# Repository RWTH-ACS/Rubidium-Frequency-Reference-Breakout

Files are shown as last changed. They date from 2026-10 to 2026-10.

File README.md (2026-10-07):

# Low-Cost Rubidium-Based Clock Reference

This project contains a hardware breakout board for an FE-5680A frequency reference, including a Python web UI to control the frequency offsets and monitor the PPS and Lock signal.

A detailed explanation is given in the publication proceedings of ISPCS 2026 (Low-Cost Rubidium-Based Clock Reference and Pulse-Per-Second Jitter Evaluation)

## Hardware

The hardware breakout board provides multiple decoupled 10 MHz outputs to allow for easy use in a laboratory environment. It also has a pulse per second output that is controllable in its pulse width.

## Software

The software stack allows for a simple control of the RFS via a Raspberry Pi. A USB to RS232 adapter that is connected to the RFS was utilized.

## License

This software is licensed under the Apache open-source license, while the hardware is under the CERN-OHL-W-2.0 open source license. Please refer to the license file in the `LICENSE` in the hardware and software directory.

We kindly ask all academic publications employing components of this work to cite the following paper:

For other licensing options please consult [Prof. Antonello Monti](mailto:amonti@eonerc.rwth-aachen.de).

## Contact

EONERC ACS Logo (http://www.acs.eonerc.rwth-aachen.de)

- Manuel Pitz <manuel.pitz@eonerc.rwth-aachen.de>
- Sebastian Uerlich <sebastian.uerlich@eonerc.rwth-aachen.de>
- Benish Khan <benish.khan@eonerc.rwth-aachen.de>
- Leonid Kalinin <leonid.kalinin@rwth-aachen.de>

[Institute for Automation of Complex Power Systems (ACS)](http://www.acs.eonerc.rwth-aachen.de)
[EON Energy Research Center (EONERC)](http://www.eonerc.rwth-aachen.de)
[RWTH University Aachen, Germany](http://www.rwth-aachen.de)

## Acknowledgment

This research has received funding from the European Union’s Horizon Europe research and innovation programme under grant agreement No 101172829. Views and opinions expressed are however those of the author(s) only and do not necessarily reflect those of the European Union or CINEA. Neither the European Union nor the granting authority can be held responsible for them.

We are grateful for the financial support of the [BMWE (Federal Ministry of Economic Affairs and Energy)](https://www.bundeswirtschaftsministerium.de/Navigation/EN/Home/home.html), funding reference [03EI6125A](https://www.enargus.de/pub/bscw.cgi/?op=enargus.eps2&q=beaver&v=10&id=243841191).

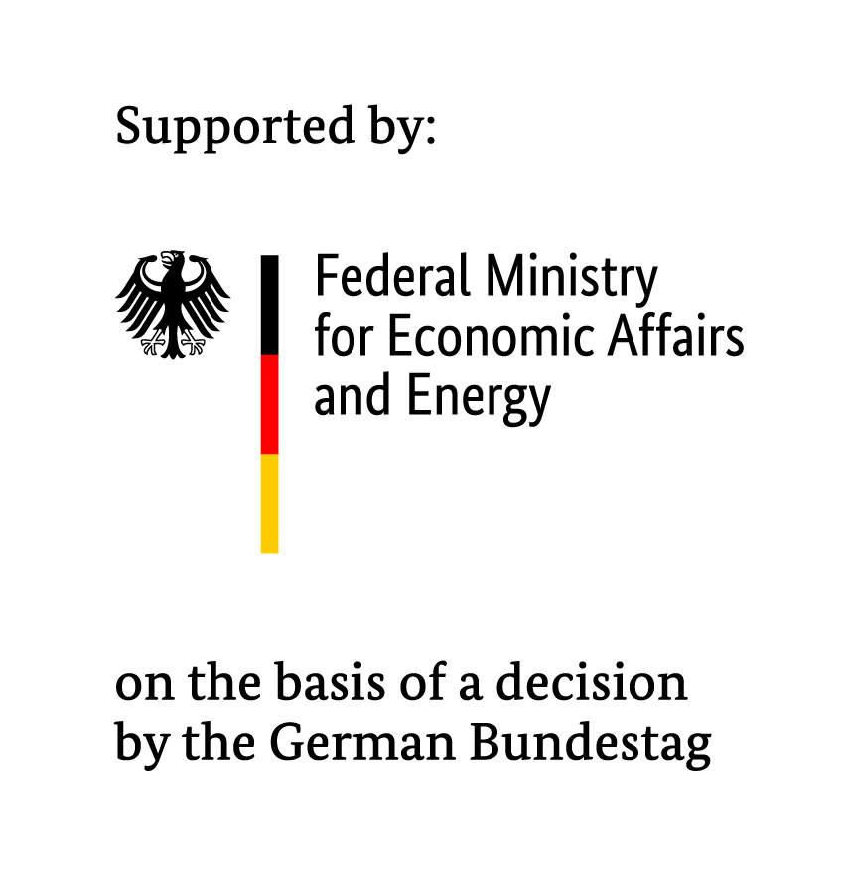
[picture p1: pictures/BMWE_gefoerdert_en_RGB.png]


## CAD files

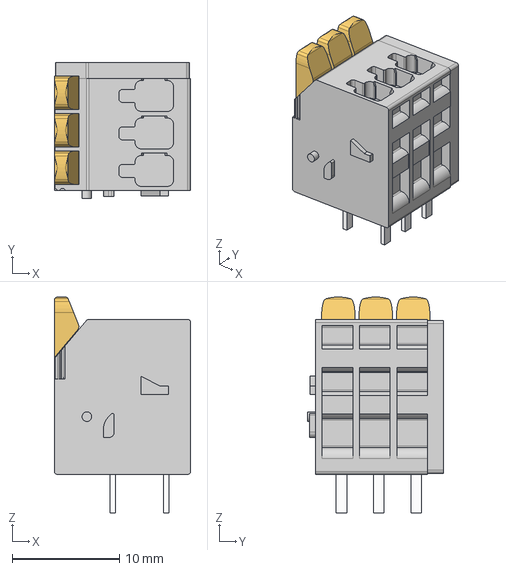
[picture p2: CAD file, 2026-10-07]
hardware/3d/2601-3103.step
12.8 x 12.8 x 20.2 mm

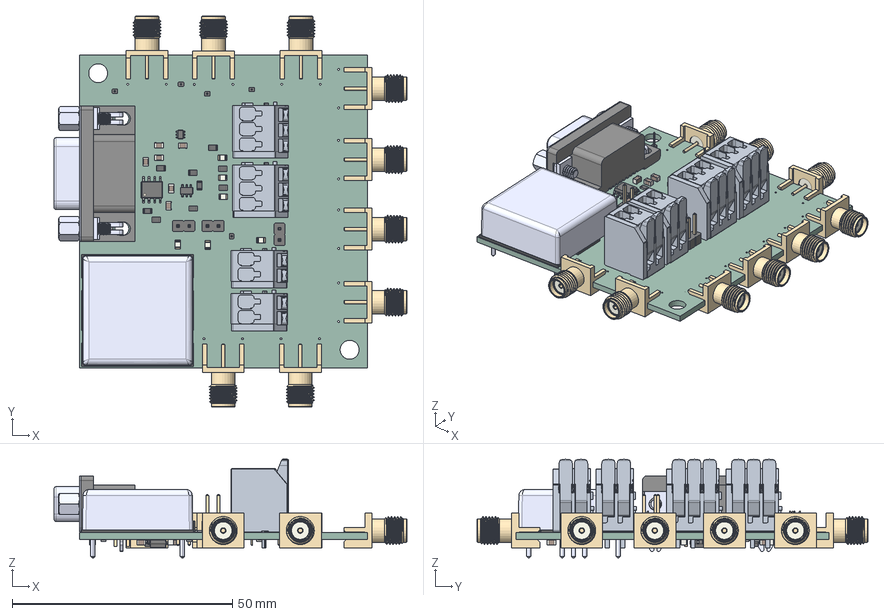
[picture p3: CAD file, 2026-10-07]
hardware/FT-5680A_interface.step
80.1 x 88.8 x 22.4 mm
SOIC-8_3.9x4.9mm_P1.27mm x 2
LED_0805_2012Metric x 6
R_0805_2012Metric x 20
SMA_Molex_73251-1153_EdgeMount_Horizontal x 9
PinHeader_1x01_P1.00mm_Vertical x 5
C_0805_2012Metric x 15
PinHeader_1x02_P2.54mm_Vertical x 3
thn15_3d_drawing
TSOT-23-6
SOT-363_SC-70-6
A-DF 09 A_KG-T2S_A-DF 09 A_KG-T2S
SSOP-16_3.9x4.9mm_P0.635mm
SOT-23-6
FT-5680A_interface_PCB

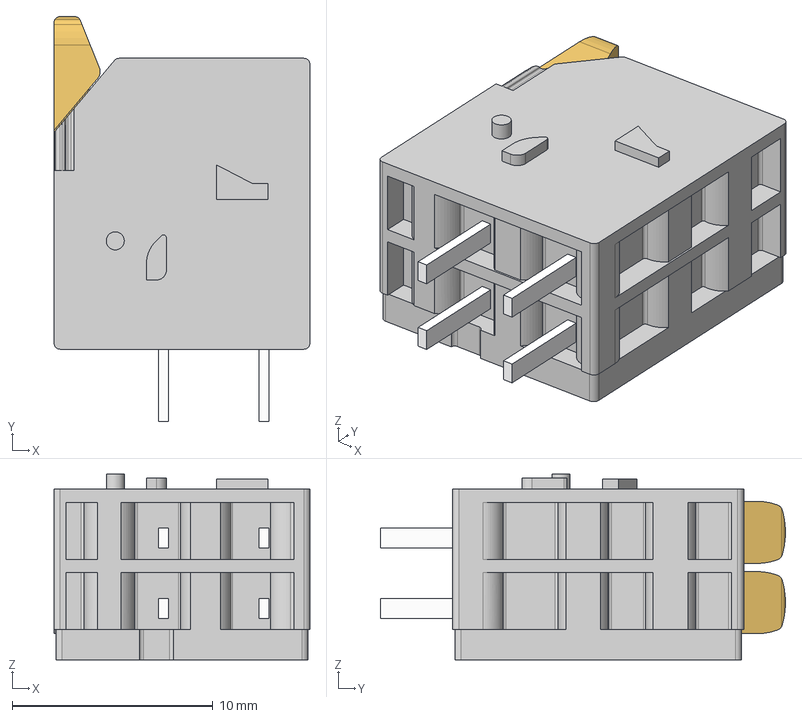
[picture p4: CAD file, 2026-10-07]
hardware/3d/2601-3102.step
12.8 x 20.2 x 9.25 mm

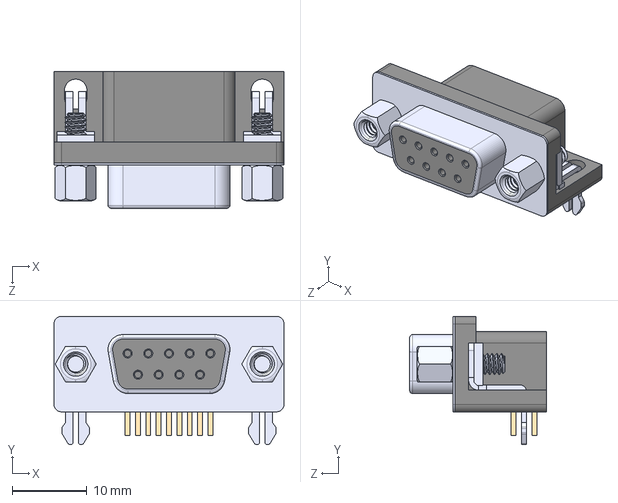
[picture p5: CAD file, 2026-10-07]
hardware/3d/A-DF_09_A_KG-T2S.step
30.8 x 17.2 x 18.3 mm

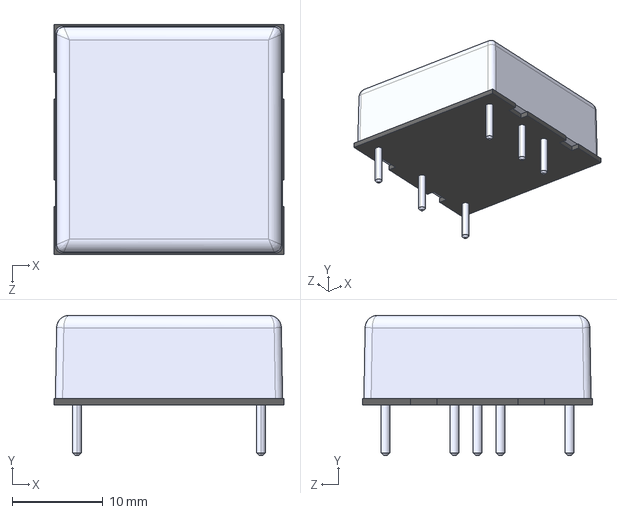
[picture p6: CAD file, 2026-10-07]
hardware/3d/thn15_3d_drawing.stp
25.4 x 15.5 x 25.4 mm

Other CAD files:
hardware/3d/2601-3102.igs
hardware/3d/2601-3103.igs

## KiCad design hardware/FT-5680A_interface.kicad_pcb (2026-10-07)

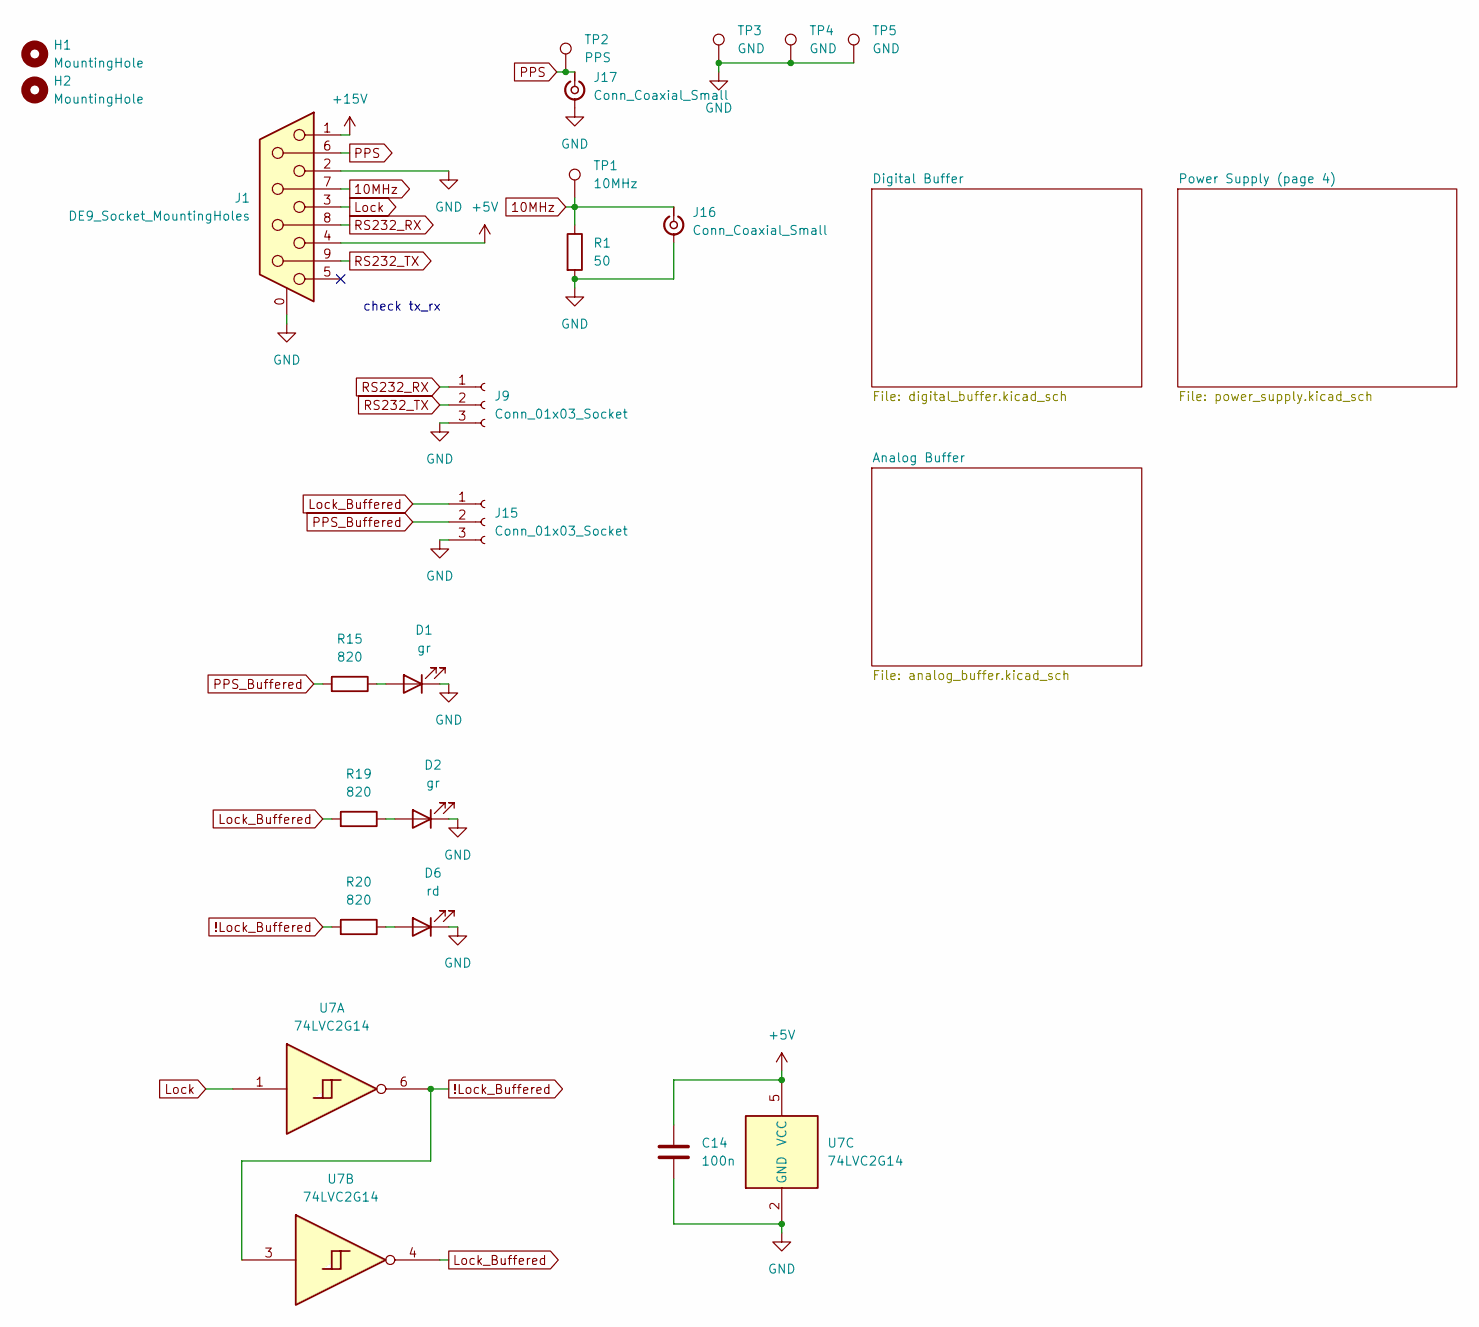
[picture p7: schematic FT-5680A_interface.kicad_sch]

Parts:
C14: 100n; C_0805_2012Metric_Pad1.18x1.45mm_HandSolder
D1, D2: gr; LED_0805_2012Metric_Pad1.15x1.40mm_HandSolder
D6: rd; LED_0805_2012Metric_Pad1.15x1.40mm_HandSolder
H1, H2: MountingHole; MountingHole_4.3mm_M4_DIN965
J1: DE9_Socket_MountingHoles; ASSMANN_A-DF_09_A_KG-T2S; Digikey AE10921-ND
J9, J15: Conn_01x03_Socket; 2601-3103; Digikey 2946-2601-3103-ND
J16, J17: Conn_Coaxial_Small; SMA_Molex_73251-1153_EdgeMount_Horizontal
R1: 50; R_0805_2012Metric_Pad1.20x1.40mm_HandSolder
R15, R19, R20: 820; R_0805_2012Metric_Pad1.20x1.40mm_HandSolder
TP1: 10MHz; PinHeader_1x01_P1.00mm_Vertical
TP2: PPS; PinHeader_1x01_P1.00mm_Vertical
TP3, TP4, TP5: GND; PinHeader_1x01_P1.00mm_Vertical
U7: 74LVC2G14; SOT-363_SC-70-6_Handsoldering; Digikey 296-13011-1-ND

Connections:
10MHz: J1.7, J16.1 (In), R1.1, TP1.1; also elsewhere on the board
!Lock_Buffered: R20.2, U7.3, U7.6
+5V: C14.1, J1.4, U7.5 (VCC); also elsewhere on the board
+15V: J1.1; also elsewhere on the board
GND: C14.2, D1.1 (K), D2.1 (K), D6.1 (K), J1.0 (PAD), J1.2, J9.3, J15.3, J16.2 (Ext), J17.2 (Ext), R1.2, TP3.1, TP4.1, TP5.1, U7.2 (GND); also elsewhere on the board
Lock: J1.3, U7.1
Lock_Buffered: J15.1, R19.2, U7.4
unnamed: D1.2 (A), R15.1
unnamed: D2.2 (A), R19.1
unnamed: D6.2 (A), R20.1
PPS: J1.6, J17.1 (In), TP2.1; also elsewhere on the board
PPS_Buffered: J15.2, R15.2; also elsewhere on the board
RS232_RX: J1.8, J9.1
RS232_TX: J1.9, J9.2

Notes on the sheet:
check tx_rx

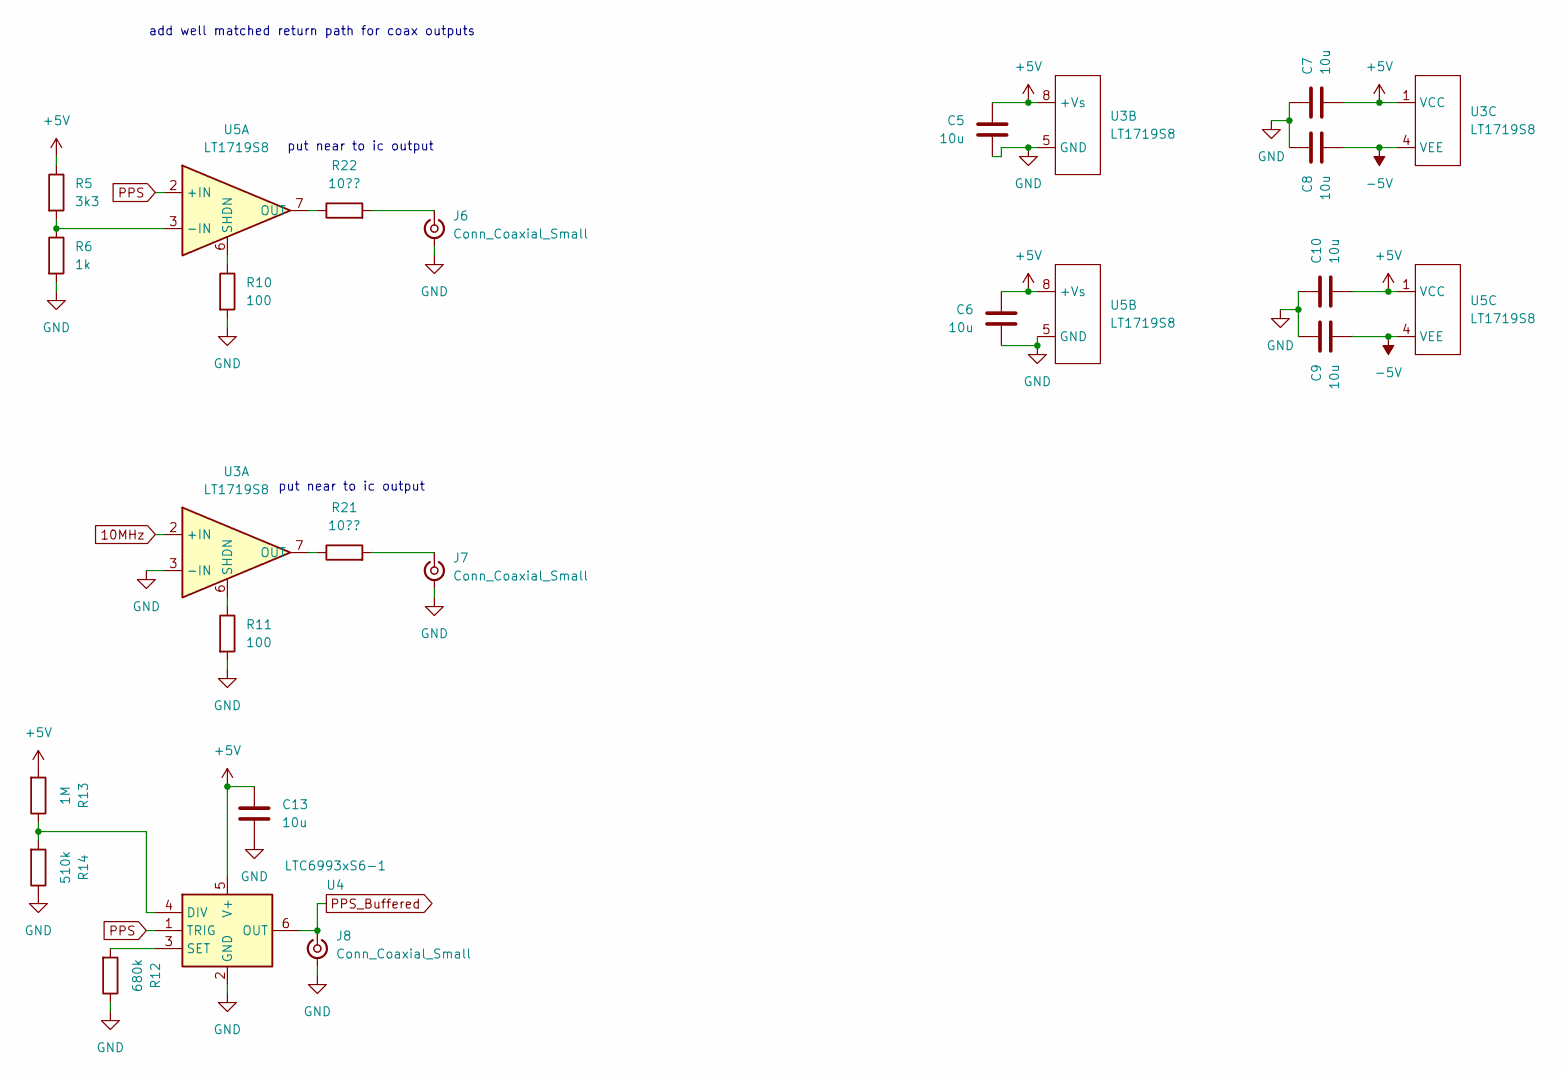
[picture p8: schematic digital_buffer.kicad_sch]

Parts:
C5, C6, C7, C8, C9, C10, C13: 10u; C_0805_2012Metric_Pad1.18x1.45mm_HandSolder
J6, J7, J8: Conn_Coaxial_Small; SMA_Molex_73251-1153_EdgeMount_Horizontal
R5: 3k3; R_0805_2012Metric_Pad1.20x1.40mm_HandSolder
R6: 1k; R_0805_2012Metric_Pad1.20x1.40mm_HandSolder
R10, R11: 100; R_0805_2012Metric_Pad1.20x1.40mm_HandSolder
R12: 680k; R_0805_2012Metric_Pad1.20x1.40mm_HandSolder
R13: 1M; R_0805_2012Metric_Pad1.20x1.40mm_HandSolder
R14: 510k; R_0805_2012Metric_Pad1.20x1.40mm_HandSolder
R21, R22: 10??; R_0805_2012Metric_Pad1.20x1.40mm_HandSolder
U3, U5: LT1719S8; SOIC-8_3.9x4.9mm_P1.27mm; Digikey 505-LT1719IS8#PBF-ND
U4: LTC6993xS6-1; TSOT-23-6_HandSoldering; Digikey 505-LTC6993HS6-1#WTRMPBFCT-ND

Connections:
10MHz: U3.2 (+IN); also elsewhere on the board
+5V: C5.1, C6.1, C7.2, C10.2, C13.1, R5.1, R13.2, U3.1 (VCC), U3.8 (+Vs), U4.5 (V+), U5.1 (VCC), U5.8 (+Vs); also elsewhere on the board
-5V: C8.2, C9.2, U3.4 (VEE), U5.4 (VEE); also elsewhere on the board
GND: C5.2, C6.2, C7.1, C8.1, C9.1, C10.1, C13.2, J6.2 (Ext), J7.2 (Ext), J8.2 (Ext), R6.2, R10.2, R11.2, R12.1, R14.1, U3.3 (-IN), U3.5 (GND), U4.2 (GND), U5.5 (GND); also elsewhere on the board
unnamed: J6.1 (In), R22.1, R22.2, U5.7 (OUT)
unnamed: J7.1 (In), R21.1, R21.2, U3.7 (OUT)
unnamed: R11.1, U3.6 (SHDN)
unnamed: R13.1, R14.2, U4.4 (DIV)
unnamed: R12.2, U4.3 (SET)
unnamed: R5.2, R6.1, U5.3 (-IN)
unnamed: R10.1, U5.6 (SHDN)
PPS: U4.1 (TRIG), U5.2 (+IN); also elsewhere on the board
PPS_Buffered: J8.1 (In), U4.6 (OUT); also elsewhere on the board

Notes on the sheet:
put near to ic output
add well matched return path for coax outputs

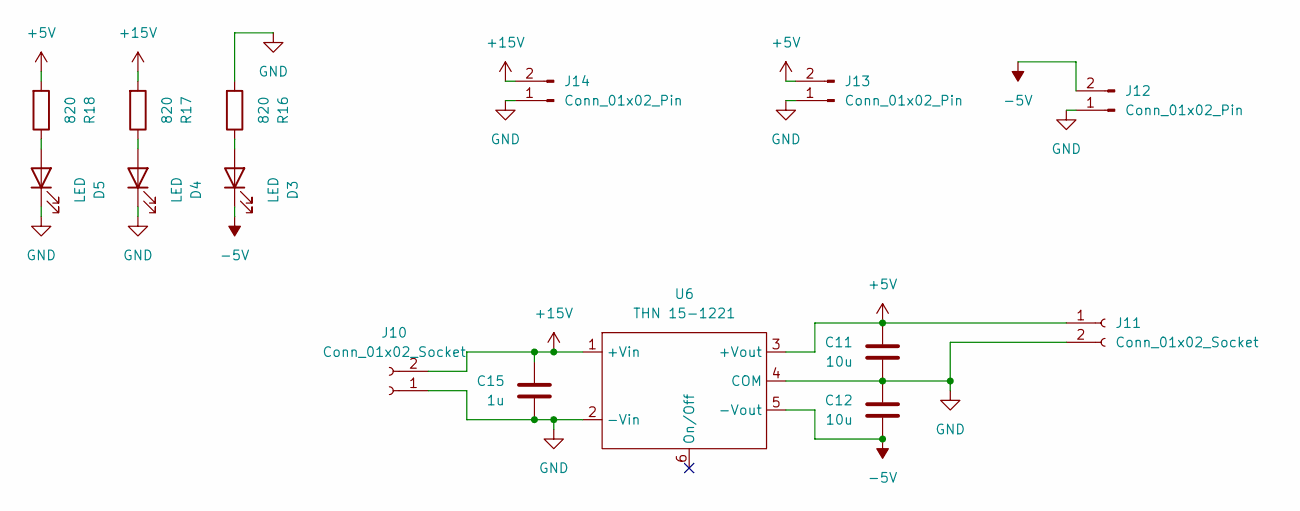
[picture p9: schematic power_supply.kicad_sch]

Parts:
C11, C12: 10u; C_0805_2012Metric_Pad1.18x1.45mm_HandSolder
C15: 1u; C_0805_2012Metric_Pad1.18x1.45mm_HandSolder
D3, D4, D5: LED; LED_0805_2012Metric_Pad1.15x1.40mm_HandSolder
J10, J11: Conn_01x02_Socket; 2601-3102; Digikey 2946-2601-3102-ND
J12, J13, J14: Conn_01x02_Pin; PinHeader_1x02_P2.54mm_Vertical
R16, R17, R18: 820; R_0805_2012Metric_Pad1.20x1.40mm_HandSolder
U6: THN 15-1221; Digikey 1951-3115-ND

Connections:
+5V: C11.1, J11.1, J13.2, R18.2, U6.3 (+Vout); also elsewhere on the board
+15V: C15.1, J10.2, J14.2, R17.2, U6.1 (+Vin); also elsewhere on the board
-5V: C12.2, D3.1 (K), J12.2, U6.5 (-Vout); also elsewhere on the board
GND: C11.2, C12.1, C15.2, D4.1 (K), D5.1 (K), J10.1, J11.2, J12.1, J13.1, J14.1, R16.2, U6.2 (-Vin), U6.4 (COM); also elsewhere on the board
unnamed: D3.2 (A), R16.1
unnamed: D4.2 (A), R17.1
unnamed: D5.2 (A), R18.1

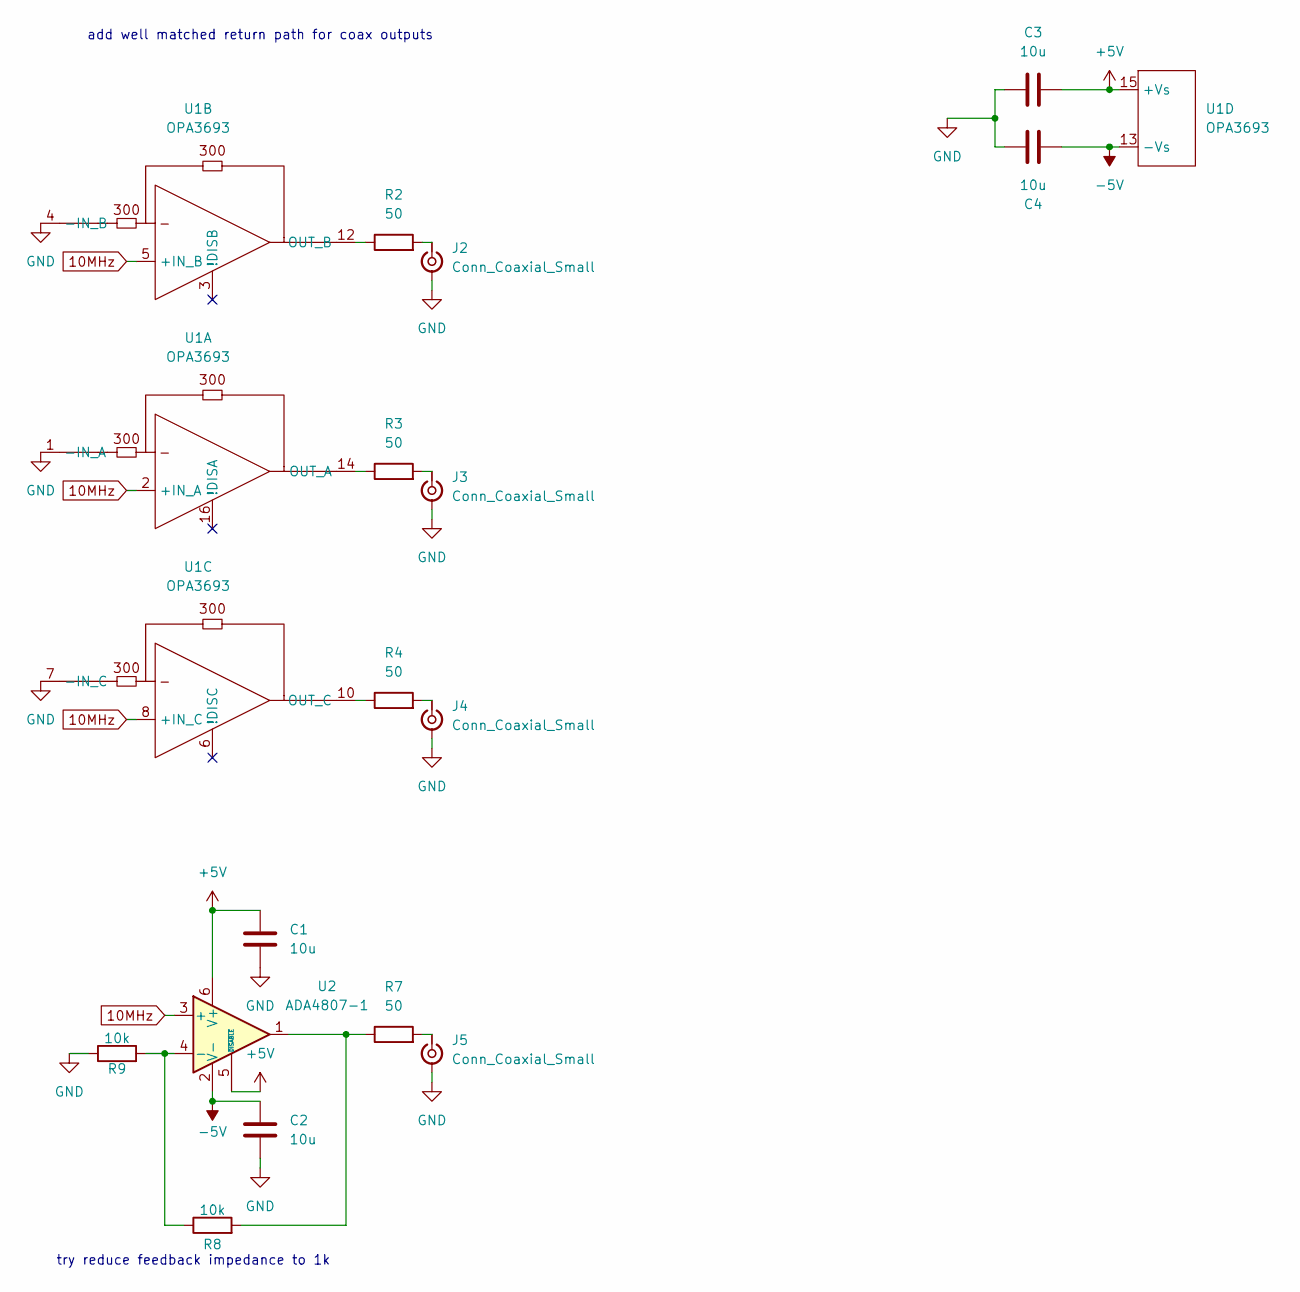
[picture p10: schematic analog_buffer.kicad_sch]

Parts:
C1, C2, C3, C4: 10u; C_0805_2012Metric_Pad1.18x1.45mm_HandSolder
J2, J3, J4, J5: Conn_Coaxial_Small; SMA_Molex_73251-1153_EdgeMount_Horizontal
R2, R3, R4, R7: 50; R_0805_2012Metric_Pad1.20x1.40mm_HandSolder
R8, R9: 10k; R_0805_2012Metric_Pad1.20x1.40mm_HandSolder
U1: OPA3693; SSOP-16_3.9x4.9mm_P0.635mm; Digikey 296-21393-5-ND
U2: ADA4807-1; SOT-23-6_Handsoldering; Digikey 505-ADA4807-1ARJZ-R7CT-ND

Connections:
10MHz: U1.2 (+IN_A), U1.5 (+IN_B), U1.8 (+IN_C), U2.3 (+); also elsewhere on the board
+5V: C1.1, C3.2, U1.11 (+Vs), U1.15 (+Vs), U2.5 (~DISABLE), U2.6 (V+); also elsewhere on the board
-5V: C2.1, C4.2, U1.9 (-Vs), U1.13 (-Vs), U2.2 (V-); also elsewhere on the board
GND: C1.2, C2.2, C3.1, C4.1, J2.2 (Ext), J3.2 (Ext), J4.2 (Ext), J5.2 (Ext), R9.1, U1.1 (-IN_A), U1.4 (-IN_B), U1.7 (-IN_C); also elsewhere on the board
unnamed: J2.1 (In), R2.2
unnamed: J3.1 (In), R3.2
unnamed: J4.1 (In), R4.2
unnamed: J5.1 (In), R7.2
unnamed: R7.1, R8.2, U2.1
unnamed: R3.1, U1.14 (OUT_A)
unnamed: R2.1, U1.12 (OUT_B)
unnamed: R4.1, U1.10 (OUT_C)
unnamed: R8.1, R9.2, U2.4 (-)

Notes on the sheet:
try reduce feedback impedance to 1k
add well matched return path for coax outputs

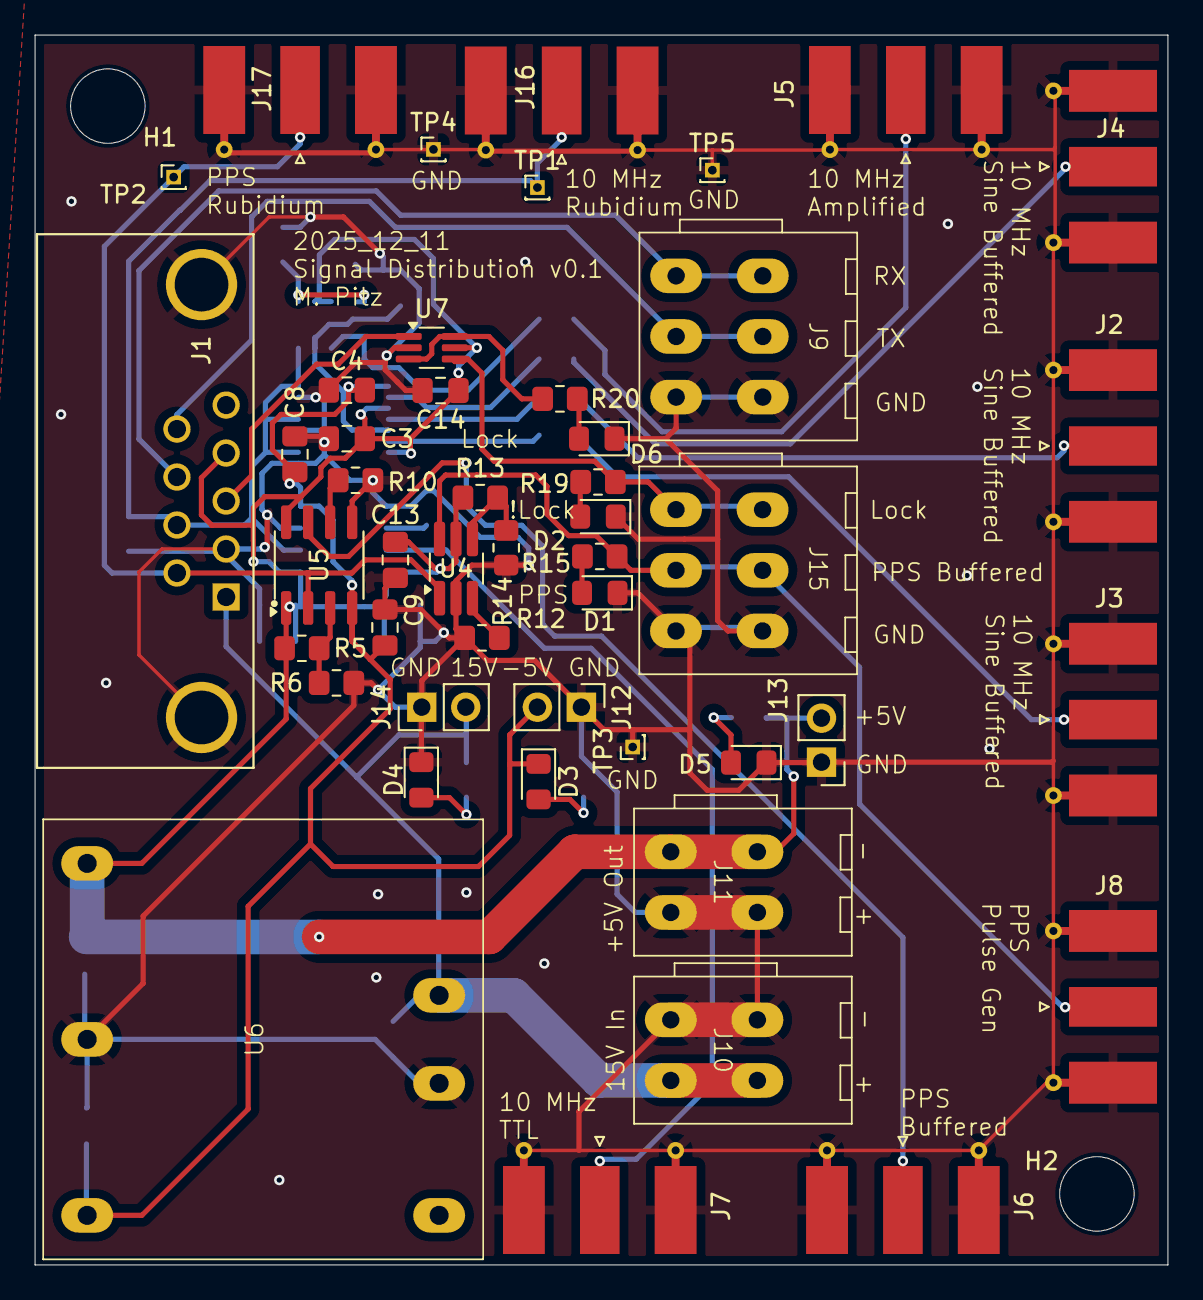
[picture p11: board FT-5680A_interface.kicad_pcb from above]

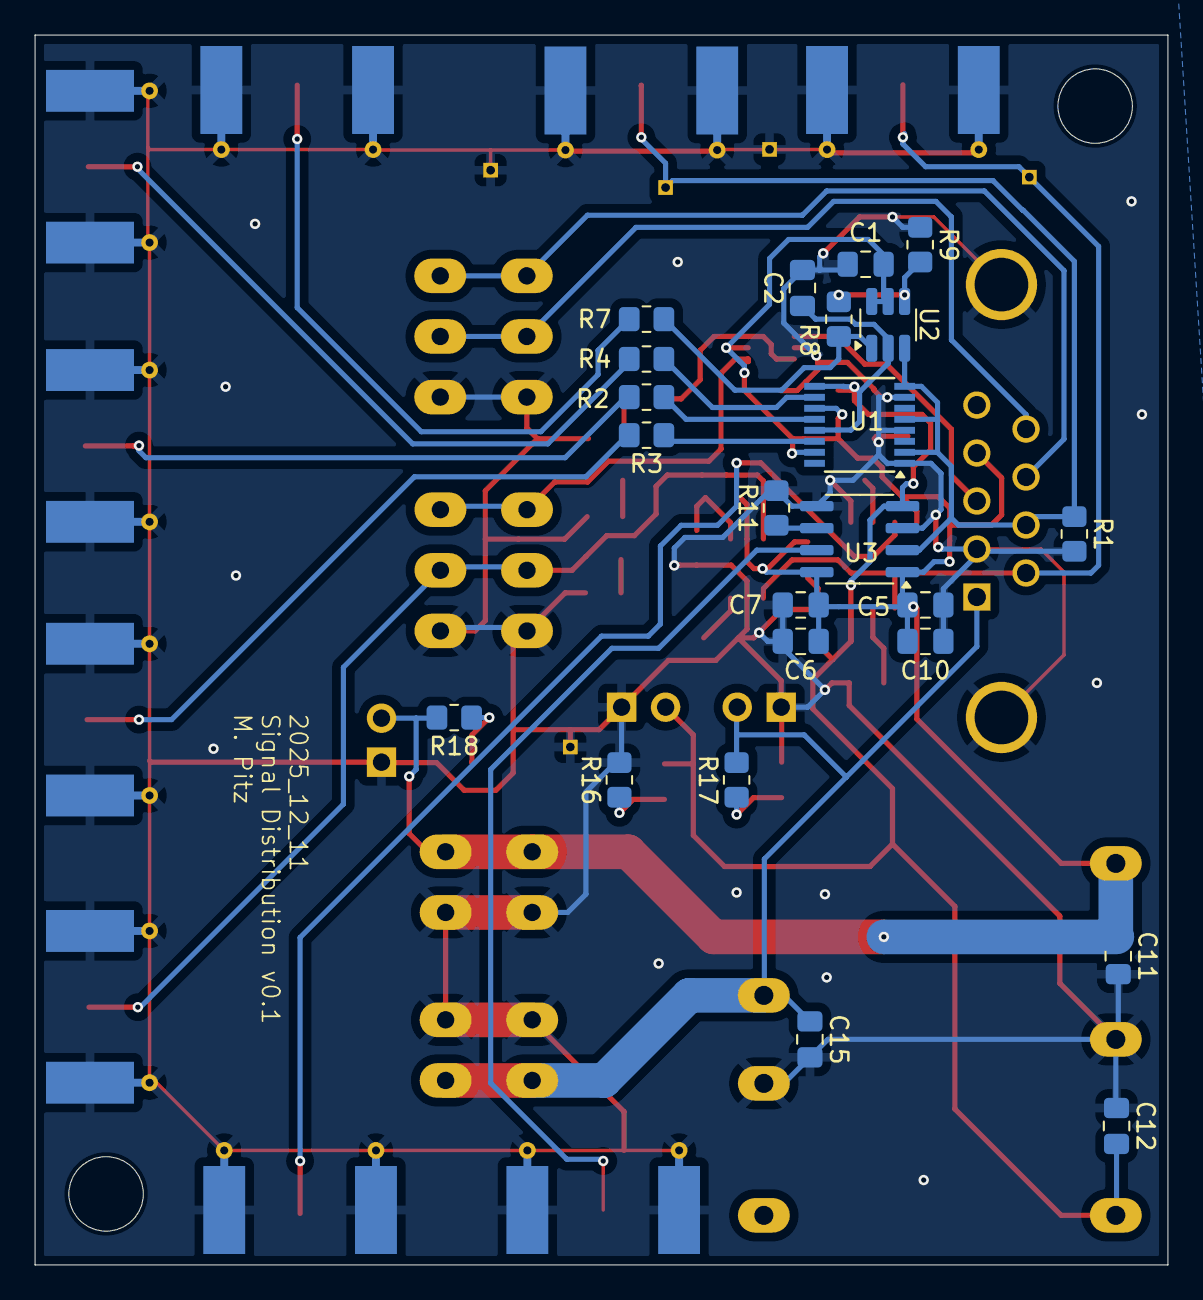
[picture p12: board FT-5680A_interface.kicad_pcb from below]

Board: 2 copper layers, 65.4 x 71.0 mm, 72 parts (23 on the bottom side), 34 nets.

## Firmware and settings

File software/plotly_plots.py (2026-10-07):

import plotly.graph_objects as go; import numpy as np
from plotly_resampler import FigureResampler, FigureWidgetResampler
from plotly.subplots import make_subplots
import pandas as pd
import plotly.graph_objects as go
from dash import Dash, dcc, html, Input, Output, callback, State


app = Dash(__name__)
app.layout = html.Div([
    html.Button("Start/Stop Update", id='start-stop-button'),
    html.Div([
        html.H4('Rubidium Setpoint History'),
        dcc.Graph(id='live-update-graph', style={'height': '2000px'}),
        dcc.Interval(
            id='interval-component',
            interval=30*1000, # in milliseconds
            n_intervals=0
        )
    ])]
)

@app.callback(
    Output('interval-component', 'disabled'),
    [Input('start-stop-button', 'n_clicks')],
    [State('interval-component', 'disabled')],
)
def callback_func_start_stop_interval(button_clicks, disabled_state):
    if button_clicks is not None and button_clicks > 0:
        return not disabled_state
    else:
        return disabled_state

# Multiple components can update everytime interval gets fired.
@callback(Output('live-update-graph', 'figure'),
              Input('interval-component', 'n_intervals'))
def update_graph_live(n):

    # df = pd.read_csv("data/2025-12-17_18_05_18.csv")
    # df.columns=["time", "phase", "setpoint", "p", "i","register", "room_temp", "device_temp", "phase2", "phase3"]

    # df['datetime'] = pd.to_datetime(df['time'], unit='s')
    # #df.datetime = df.datetime.dt.tz_localize('UTC').dt.tz_convert("Europe/Berlin")
    # df.datetime= df.datetime + pd.DateOffset(hours=1)
    # df.set_index("datetime", inplace=True)
    # df.drop(df.head(23000).index,inplace=True)


    # df_1 = pd.read_csv("data/2025-12-27_08_11_22.csv")
    # df_1.columns=["time", "phase", "setpoint", "p", "i","register", "room_temp", "device_temp", "phase2", "phase3"]

    # df_1['datetime'] = pd.to_datetime(df_1['time'], unit='s')
    # #df.datetime = df.datetime.dt.tz_localize('UTC').dt.tz_convert("Europe/Berlin")
    # df_1.datetime= df_1.datetime + pd.DateOffset(hours=1)
    # df_1.set_index("datetime", inplace=True)
    # df_1.drop(df_1.head(1000).index,inplace=True)

    # #df = pd.concat([df_0, df_1], ignore_index=True)


    # df = pd.concat([df, df_1],axis=0)


    df = pd.read_csv("data/2026-01-18_15_00_07.csv")
    df.columns=["time", "phase", "setpoint", "p", "i","register", "room_temp", "device_temp", "phase2", "phase3"]

    df['datetime'] = pd.to_datetime(df['time'], unit='s')
    #df.datetime = df.datetime.dt.tz_localize('UTC').dt.tz_convert("Europe/Berlin")
    df.datetime= df.datetime + pd.DateOffset(hours=1)
    df.set_index("datetime", inplace=True)
    #df.drop(df.head(23000).index,inplace=True)

    
    #dfs = list()
    #for f in files:
    #    d = pd.read_csv(f, index_col=None)
    #    dfs.append(d)
        
    #df = pd.concat(dfs, ignore_index=True)
    


    # df['datetime'] = pd.to_datetime(df['time'], unit='s')
    # #df.datetime = df.datetime.dt.tz_localize('UTC').dt.tz_convert("Europe/Berlin")
    # df.datetime= df.datetime + pd.DateOffset(hours=1)
    # df.set_index("datetime", inplace=True)

    fig = FigureResampler(make_subplots(rows=7, cols=1,shared_xaxes=True, vertical_spacing=0.01))


    fig.add_trace(
        go.Scattergl(
            name = "Integral",
    #        x = df["time"].values ,
    #        y = df["i"].values,
            showlegend = True,
            #y="Integral [Hz]"
        ),
        hf_x = df.index,
        hf_y = df["i"].values,
        row = 1,
        col = 1
    )

    fig.add_trace(
        go.Scattergl(
            name = "Proportional",
            showlegend = True,
            #y="Proportional [Hz]"
        ),
        hf_x = df.index,
        hf_y = df["p"].values,
        row = 2,
        col = 1
    )
    fig.add_trace(
        go.Scattergl(
            name = "Setpoint",
            showlegend = True,
            #y="Setpoint [Hz]"
        ),
        hf_x = df.index,
        hf_y = df["setpoint"].values,
        row = 3,
        col = 1
    )
    fig.add_trace(
        go.Scattergl(
            name = "Phase",
            showlegend = True,
            #y="Phase [Deg]"
        ),
        hf_x = df.index,
        hf_y = df["phase"].values,
        row = 4,
        col = 1
    )

    fig.add_trace(
        go.Scattergl(
            name = "Room_Temp",
            showlegend = True,
            #y="Temperature [Degree]"
        ),
        hf_x = df.index,
        hf_y = df["room_temp"].values,
        row = 5,
        col = 1
    )

    fig.add_trace(
        go.Scattergl(
            name = "Device_Temp",
            showlegend = True,
            #y="Temperature [Degree]"
        ),
        hf_x = df.index,
        hf_y = df["device_temp"].values,
        row = 6,
        col = 1
    )
    fig.add_trace(
        go.Scattergl(
            name = "Phase Buffered 10 MHz 1",
            showlegend = True,
            #y="Phase [Deg]"

        ),
        hf_x = df.index,
        hf_y = df["phase2"].values,
        row = 7,
        col = 1
    )
    fig.add_trace(
        go.Scattergl(
            name = "Phase Buffered 10 MHz 2",
            showlegend = True,
        ),
        hf_x = df.index,
        hf_y = df["phase3"].values,
        row = 7,
        col = 1
    )

    dow = df.index.to_series().dt.dayofweek
    change_mask = dow.ne(dow.shift())
    change_idx = df.index[change_mask]
    change_idx = change_idx.append(df.index[-1:])
    s = None
    c = 1
    for e in change_idx:
        if s is None:
            s = e
            continue
        if c%2 == 0:
            fig.add_vrect(
                x0=s.round('s'), x1=e.round('s'),
                fillcolor="LightSalmon", opacity=0.2,
                layer="below", line_width=0,
            )
        s = e
        c += 1



    fig.update_layout(title='', title_x=0, margin= {'l': 0, 'r': 0, 't': 0, 'b': 0})#, height=1500)

    #fig.show_dash(mode='inline',debug=False, host='0.0.0.0')
    return fig

if __name__ == '__main__':
    app.run(debug=True, host="0.0.0.0")

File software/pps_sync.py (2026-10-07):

from rubidium import RUBI
import time
import RsInstrument as rsi
from datetime import datetime
import logging, coloredlogs
import tyro
import os
from classes.PI import PI

logger = logging.getLogger(__name__)

####
# pps_sync.py --name rubi0 --serial_port /dev/ttyUSB0 --scope TCPIP::number42.acs-lab.eonerc.rwth-aachen.de::hislip0 --measurement MEASurement1:RESult:ACTual? --p 5e6 --i 1e-5 --log_level DEBUG

####
def main(
        name : str,
        serial_port: str,
        scope: str,
        measurement: str,
        p: float = 1.0,
        i: str = 1.0,
        log_level: str = "DEBUG"
):
    """Isolator test bench CLI

    Args:
        name: Name of the device
        serial_port: Path to serial port
        scope: url of scope
        measurement: the measurement string to receive phase
        p: proportional value
        i: integral value
        log_level: The log level
    """

    coloredlogs.install(level=log_level,
    fmt='%(asctime)s %(levelname)-8s %(name)s[%(process)d] %(message)s',
    field_styles=dict(
        asctime=dict(color='green'),
        hostname=dict(color='magenta'),
        levelname=dict(color='white', bold=True),
        programname=dict(color='cyan'),
        name=dict(color='blue')))
    logger.info("Isolator test bench started.")


    step = 6.8126e-6

    if not os.path.exists(serial_port):
        raise Exception(f"Serial port {serial_port} does not exists")
    rubi = RUBI(serial_port)
    rubi_pi = PI(rubi.current_value_float)

    mxo = rsi.RsInstrument(scope)
    mxo.write('SYSTem:DISPlay:UPDate ON')
    delay = mxo.query_float(measurement)
    logging.info(f"{name} Setpoint:{rubi.current_value_float:.12f};  Delay:{delay:.12f}")

    now = datetime.now()

    fh = open(f"data/{name}pps_" + now.strftime("%Y-%m-%d_%H_%M_%S") + ".csv", "a")
    #fh = open("data/pps_2026-02-24_12_05_28.csv", "a")

    while True:
        delay = mxo.query_float(measurement)
        rubi_pi.update(delay)
        if abs(rubi_pi.now - rubi_pi.last) > step:
            if rubi.write_value(rubi.float_to_value(rubi_pi.now)):
                print("New Setpoint send")
        logging.info(f"{name} Setpoint:{rubi.current_value_float:.12f};  Delay:{delay:.12f}")

        fh.write(f"{time.time()};{rubi.current_value_float:.12f};{delay:.12f}\n")
        fh.flush()
        
        time.sleep(1)

if __name__ == "__main__":
    tyro.cli(main)


# step = 6.8126e-6
# i = 0
# pass

# rubi0 = RUBI("/dev/ttyUSB0", enable_update = False) 
# rubi1 = RUBI("/dev/ttyUSB1", limit = 0.3) 
# rubi2 = RUBI("/dev/ttyUSB3", enable_update = False)

# rubi0_pi = PI(rubi0.current_value_float)
# rubi1_pi = PI(rubi1.current_value_float)
# rubi2_pi = PI(rubi2.current_value_float)

# logging.warning(f"Current Setpoint\t rubi0:{rubi0.current_value_float}\t rubi1:{rubi1.current_value_float}\trubi2:{rubi2.current_value_float}")

# now = datetime.now()

# fh = open("data/pps_" + now.strftime("%Y-%m-%d_%H_%M_%S") + ".csv", "a")
# #fh = open("data/pps_2026-02-24_12_05_28.csv", "a")


# mxo = rsi.RsInstrument('TCPIP::number42.acs-lab.eonerc.rwth-aachen.de::hislip0')
# mxo.write('SYSTem:DISPlay:UPDate ON')

# while True:

#     delay_rubi0 = mxo.query_float('MEASurement1:RESult:ACTual?')
#     delay_rubi1 = mxo.query_float('MEASurement2:RESult:ACTual?')
#     delay_rubi2 = mxo.query_float('MEASurement3:RESult:ACTual?')


#     rubi0_pi.update(delay_rubi0)
#     if abs(rubi0_pi.now - rubi0_pi.last) > step:
#         if rubi0.write_value(rubi0.float_to_value(rubi0_pi.now)):
#             print("New Setpoint send rubi 0")

#     rubi1_pi.update(delay_rubi1)
#     if abs(rubi1_pi.now - rubi0_pi.last) > step:
#         if rubi1.write_value(rubi1.float_to_value(rubi1_pi.now)):
#             print("New Setpoint send rubi 1")

#     rubi2_pi.update(delay_rubi2)
#     if abs(rubi2_pi.now - rubi0_pi.last) > step:
#         if rubi2.write_value(rubi2.float_to_value(rubi2_pi.now)):
#             print("New Setpoint send rubi 2")

#     print(f"rubi0_setp:{rubi0.current_value_float:.12f};  rubi0_delay:{delay_rubi0:.12f}\trubi1_setp:{rubi1.current_value_float:.12f};  rubi1_delay:{delay_rubi1:.12f}\trubi2_setp: {rubi2.current_value_float:.12f};  rubi2_delay:{delay_rubi2:.12f}")
#     #print(f"\t\t")
    
    
#     fh.write(f"{time.time()};{rubi0.current_value_float:.12f};{delay_rubi0:.12f};{rubi1.current_value_float:.12f};{delay_rubi1:.12f};{rubi2.current_value_float:.12f};{delay_rubi2:.12f}\n")
#     fh.flush()
#     #f"{time.time()},{phase},{value},{pi.p},{pi.i},{rubidium.byte_to_hexstring(setpoint)},{devs[0].get_temperatures(sensors=sensors)[0]['temperature_c']},{devs[1].get_temperatures(sensors=sensors)[0]['temperature_c']},{ref_phasej3},{ref_phasej4}\n")
 

#     time.sleep(1)

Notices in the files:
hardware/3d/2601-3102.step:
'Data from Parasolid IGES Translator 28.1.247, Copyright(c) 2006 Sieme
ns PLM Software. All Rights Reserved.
